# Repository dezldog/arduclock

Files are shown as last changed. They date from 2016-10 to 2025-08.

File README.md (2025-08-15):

# Instructions for `arduclock`

## Project Overview
This repository contains Arduino-based GPS clock projects with 7-segment displays. There are three main variants:
- `gps_clock_auto_timezone/`: GPS clock with automatic timezone detection based on GPS location.
- `gps_clock_tz_dst/`: GPS clock with manual DST and timezone selection via hardware pins.
- `original/`: Early version with manual UTC offset and DST toggle.

## Architecture & Key Files
- Each variant is a standalone `.ino` file, using similar hardware and libraries:
  - `Adafruit_LEDBackpack`, `Adafruit_GFX`, `Adafruit_GPS`, `SoftwareSerial`, `Wire`
- Hardware pins for timezone/DST selection are defined in each file (see `Config` namespace or `#define` macros).
- Display updates and GPS polling are managed via periodic intervals (see `DISPLAY_UPDATE_MS`, `TIMEZONE_CHECK_MS`, etc.).
- Timezone logic:
  - `gps_clock_auto_timezone`: Uses GPS coordinates to set timezone automatically.
  - `gps_clock_tz_dst`: Uses hardware pins for manual selection.
  - `original`: Uses fixed UTC offset and DST toggle.

## Developer Workflows
- **Build/Upload:**
  - Open the desired `.ino` file in the Arduino IDE or VS Code with Arduino extension.
  - Select the correct board and port, then upload as usual.
- **Debugging:**
  - Use `Serial.begin(115200)` for serial output (default baud rate).
  - Monitor serial output for GPS data and time updates.
- **Dependencies:**
  - Install required libraries via Arduino Library Manager:
    - Adafruit_LEDBackpack
    - Adafruit_GFX
    - Adafruit_GPS
    - SoftwareSerial
    - Wire (built-in)

## Project-Specific Patterns & Conventions
- **Pin Assignments:**
  - Timezone/DST selection pins are consistently assigned (see `Config` or macros).
  - GPS RX/TX pins: 8/7 (all variants).
- **Display Address:**
  - I2C address for display is `0x70`.
- **Time Format:**
  - 12-hour format by default (`TIME_24_HOUR = false`).
- **Serial Baud Rates:**
  - GPS: 9600
  - Serial Monitor: 115200
- **Update Intervals:**
  - Display: 100ms
  - Timezone check: 1s
  - Location check (auto mode): 30s

## Integration Points
- **External Services:**
  - No network/cloud integration; all logic is local to the Arduino.
- **PCB Files:**
  - Hardware design files in `original/` (`main_board.brd`, `.sch`).
  - Order PCBs via OSH Park (see README).

## Example: Adding a New Variant
- Copy an existing `.ino` file and update pin assignments, display logic, or timezone handling as needed.
- Follow the established pattern for hardware initialization and periodic updates.

## References
- Key files: `gps_clock_auto_timezone/gps_clock_auto_tz.ino`, `gps_clock_tz_dst/gps_clock_tz_dst.ino`, `original/clock_dst_tz.ino`
- Hardware: See `original/main_board.brd` and `.sch`
- README: Contains PCB ordering info and project links

---
**If any section is unclear or missing details, please provide feedback so this guide can be improved.**

View this project on [CADLAB.io](https://cadlab.io/node/898). 

# arduclock
PWBs available @

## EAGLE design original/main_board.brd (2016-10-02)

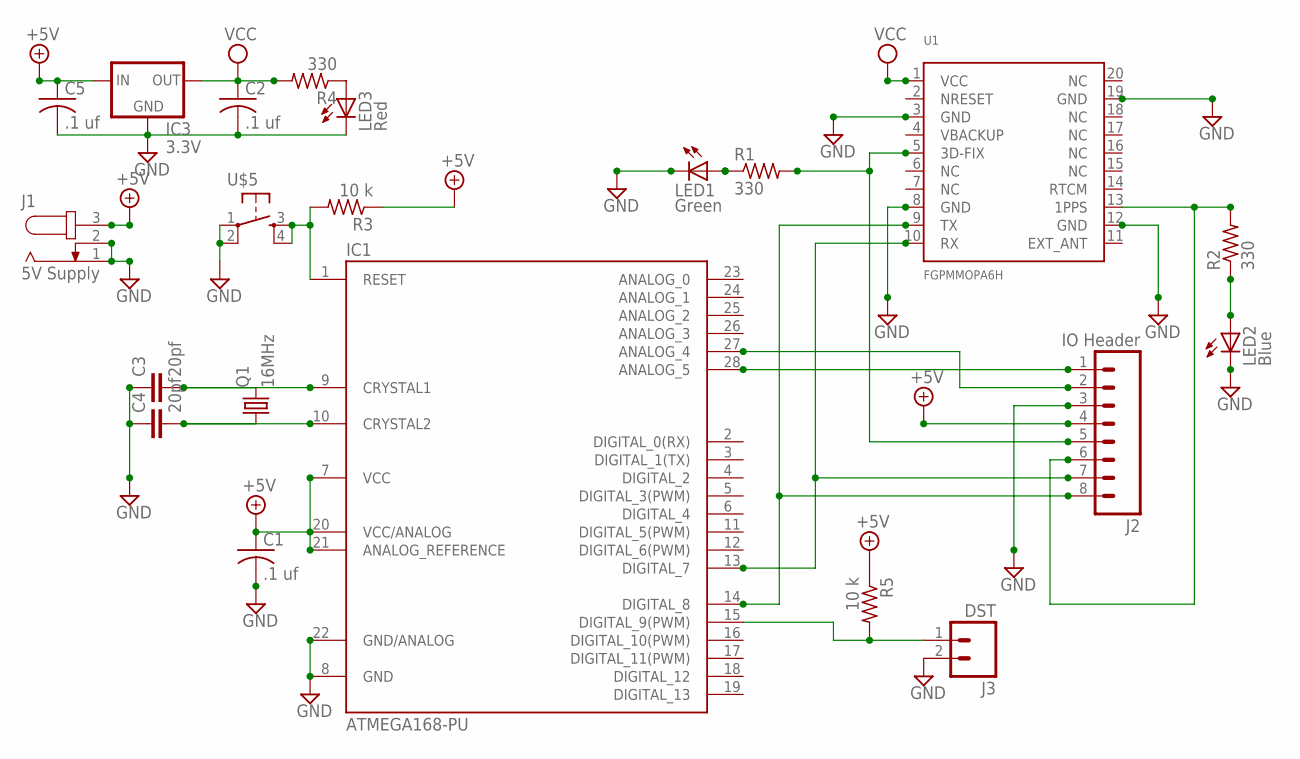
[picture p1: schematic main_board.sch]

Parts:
C1, C2, C5: .1 uf; C025-025X050
C3, C4: 20pf; C025-024X044
IC1: ATMEGA168-PU; DIL28-3
IC3: 3.3V; TO92
J1: 5V Supply; SPC4078
J2: IO Header; 1X08_ROUND
J3: DST; 1X02_LOCK
LED1: Green; LED3MM
LED2: Blue; LED3MM
LED3: Red; LED3MM
Q1: 16MHz; HC18U-V
R1, R2, R4: 330; 0204/5
R3, R5: 10 k; 0204/5
U1: FGPMMOPA6H
U$5: TACTILE-SWITCH-PTH; TAC-SWITCH-PTH

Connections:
+5V: C1.1, C5.1, IC1.7 (VCC), IC1.20 (VCC/ANALOG), IC1.21 (ANALOG_REFERENCE), IC3.2 (IN), J1.3, J2.4, R3.1, R5.1
DST: IC1.15 (DIGITAL_9(PWM)), J3.1, R5.2
GND: C1.2, C2.2, C3.1, C4.1, C5.2, IC1.8 (GND), IC1.22 (GND/ANALOG), IC3.1 (GND), J1.1, J1.2, J2.3, J3.2, LED1.K (C), LED2.K (C), LED3.K (C), U1.3 (GND), U1.8 (GND), U1.12 (GND), U1.19 (GND), U$5.1, U$5.2
unnamed: C4.2, IC1.10 (CRYSTAL2), Q1.1
unnamed: C3.2, IC1.9 (CRYSTAL1), Q1.2
unnamed: IC1.13 (DIGITAL_7), J2.7, U1.10 (RX)
unnamed: IC1.14 (DIGITAL_8), J2.8, U1.9 (TX)
unnamed: LED3.A, R4.1
unnamed: IC1.28 (ANALOG_5), J2.1
unnamed: IC1.1 (RESET), R3.2, U$5.3, U$5.4
unnamed: IC1.27 (ANALOG_4), J2.2
unnamed: J2.6, R2.2, U1.13 (1PPS)
unnamed: J2.5, R1.2, U1.5 (3D-FIX)
unnamed: LED1.A, R1.1
unnamed: LED2.A, R2.1
VCC: C2.1, IC3.3 (OUT), R4.2, U1.1 (VCC)

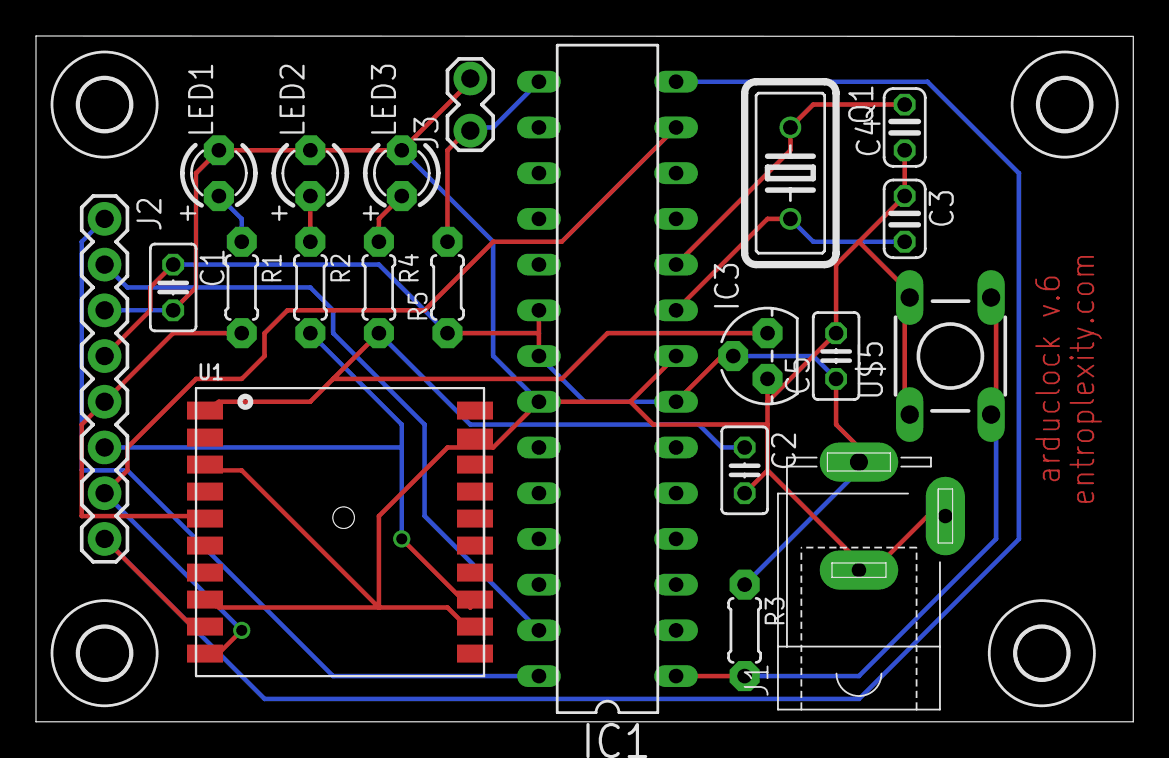
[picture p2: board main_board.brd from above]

Board: 2 copper layers, 61.0 x 38.1 mm, 25 parts (0 on the bottom side), 16 nets.

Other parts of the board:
U$1, U$2, U$3, U$4: 2,8

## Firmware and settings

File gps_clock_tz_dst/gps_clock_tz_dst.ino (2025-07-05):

/**
 * GPS Clock with 7-Segment Display
 * and DST/TimeZone selector
 */

#include "SoftwareSerial.h"
#include "Wire.h"
#include "Adafruit_LEDBackpack.h"
#include "Adafruit_GFX.h"
#include "Adafruit_GPS.h"

// Configuration Constants
namespace Config {
  // Display settings
  const bool TIME_24_HOUR = false;
  const uint8_t DISPLAY_ADDRESS = 0x70;
  
  // Time zone settings
  const uint8_t DST_PIN = 9;           // Pin for DST switch
  const uint8_t TIMEZONE_PIN_A = 10;   // Pin A for timezone selection
  const uint8_t TIMEZONE_PIN_B = 11;   // Pin B for timezone selection
  const uint8_t TIMEZONE_PIN_C = 12;   // Pin C for timezone selection
  
  // GPS settings
  const uint8_t GPS_RX_PIN = 8;
  const uint8_t GPS_TX_PIN = 7;
  const uint32_t GPS_BAUD = 9600;
  const uint32_t SERIAL_BAUD = 115200;
  
  // Update intervals
  const uint16_t DISPLAY_UPDATE_MS = 100;
  const uint16_t TIMEZONE_CHECK_MS = 1000;  // Check timezone switches every second
}

// Hardware instances
Adafruit_7segment display = Adafruit_7segment();
SoftwareSerial gpsSerial(Config::GPS_RX_PIN, Config::GPS_TX_PIN);
Adafruit_GPS gps(&gpsSerial);

// Timezone definitions
struct Timezone {
  const char* name;
  const char* abbreviation;
  int8_t utcOffset;        // Standard time offset from UTC
  bool observesDST;        // Whether this timezone observes DST
  int8_t dstOffset;        // Additional offset during DST (usually +1)
};

// Predefined timezones (expandable)
const Timezone TIMEZONES[] = {
  {"Pacific Standard", "PST", -8, true, 1},      // 000
  {"Mountain Standard", "MST", -7, true, 1},     // 001
  {"Central Standard", "CST", -6, true, 1},      // 010
  {"Eastern Standard", "EST", -5, true, 1},      // 011
  {"Atlantic Standard", "AST", -4, false, 0},    // 100
  {"Hawaii Standard", "HST", -10, false, 0},     // 101
  {"Alaska Standard", "AKST", -9, true, 1},      // 110
  {"UTC", "UTC", 0, false, 0}                    // 111
};

const uint8_t NUM_TIMEZONES = sizeof(TIMEZONES) / sizeof(TIMEZONES[0]);

// State variables
struct ClockState {
  uint32_t lastUpdate = 0;
  uint32_t lastTimezoneCheck = 0;
  bool colonState = false;
  bool gpsFixValid = false;
  uint8_t hours = 0;
  uint8_t minutes = 0;
  uint8_t seconds = 0;
  uint8_t currentTimezoneIndex = 0;
  bool isDSTActive = false;
  bool dstSwitchState = false;
  uint8_t timezoneSwitchState = 0;
} clockState;

/**
 * Initialize all hardware components
 */
void setup() {
  Serial.begin(Config::SERIAL_BAUD);
  Serial.println(F("GPS Clock Starting..."));
  
  initializeDisplay();
  initializeGPS();
  initializePins();
  
  Serial.println(F("Initialization complete"));
}

/**
 * Main program loop
 */
void loop() {
  updateGPSData();
  updateTimezoneIfNeeded();
  
  if (millis() - clockState.lastUpdate >= Config::DISPLAY_UPDATE_MS) {
    updateDisplay();
    clockState.lastUpdate = millis();
  }
}

/**
 * Initialize the 7-segment display
 */
void initializeDisplay() {
  display.begin(Config::DISPLAY_ADDRESS);
  display.setBrightness(15);  // Max brightness
  
  // Show startup pattern
  display.print(8888);
  display.drawColon(true);
  display.writeDisplay();
  delay(1000);
  display.clear();
  display.writeDisplay();
}

/**
 * Initialize GPS module
 */
void initializeGPS() {
  gps.begin(Config::GPS_BAUD);
  
  // Configure GPS for optimal clock usage
  gps.sendCommand(PMTK_SET_NMEA_OUTPUT_RMCONLY);
  gps.sendCommand(PMTK_SET_NMEA_UPDATE_1HZ);
  
  enableGPSInterrupt();
  
  Serial.println(F("Waiting for GPS fix..."));
}

/**
 * Initialize input pins
 */
void initializePins() {
  pinMode(Config::DST_PIN, INPUT_PULLUP);
  pinMode(Config::TIMEZONE_PIN_A, INPUT_PULLUP);
  pinMode(Config::TIMEZONE_PIN_B, INPUT_PULLUP);
  pinMode(Config::TIMEZONE_PIN_C, INPUT_PULLUP);
  
  // Initialize timezone state
  updateTimezoneSettings();
  
  Serial.print(F("Initial timezone: "));
  Serial.println(getCurrentTimezone().name);
}

/**
 * Update GPS data if available
 */
void updateGPSData() {
  if (gps.newNMEAreceived()) {
    if (gps.parse(gps.lastNMEA())) {
      clockState.gpsFixValid = gps.fix;
      
      if (clockState.gpsFixValid) {
        updateTimeFromGPS();
      }
    }
  }
}

/**
 * Extract and adjust time from GPS data
 */
void updateTimeFromGPS() {
  int totalOffset = calculateTimezoneOffset();
  int adjustedHours = gps.hour + totalOffset;
  
  // Handle day boundary crossings
  adjustedHours = normalizeHours(adjustedHours);
  
  clockState.hours = adjustedHours;
  clockState.minutes = gps.minute;
  clockState.seconds = gps.seconds;
}

/**
 * Normalize hours to 0-23 range, handling day boundaries
 */
int normalizeHours(int hours) {
  while (hours < 0) {
    hours += 24;
  }
  while (hours >= 24) {
    hours -= 24;
  }
  return hours;
}

/**
 * Update the display with current time
 */
void updateDisplay() {
  if (!clockState.gpsFixValid) {
    showNoGPSIndicator();
    return;
  }
  
  int displayHours = clockState.hours;
  int displayValue;
  
  // Convert to 12-hour format if needed
  if (!Config::TIME_24_HOUR) {
    displayHours = convertTo12Hour(displayHours);
  }
  
  displayValue = displayHours * 100 + clockState.minutes;
  
  // Display the time
  display.print(displayValue, DEC);
  
  // Handle leading zeros for 24-hour format
  if (Config::TIME_24_HOUR && clockState.hours < 10) {
    display.writeDigitNum(1, 0);
    if (clockState.minutes < 10) {
      display.writeDigitNum(3, 0);
    }
  }
  
  // Blink colon every second
  bool showColon = (clockState.seconds % 2 == 0);
  display.drawColon(showColon);
  
  display.writeDisplay();
}

/**
 * Convert 24-hour format to 12-hour format
 */
int convertTo12Hour(int hours24) {
  if (hours24 == 0) {
    return 12;  // Midnight becomes 12 AM
  } else if (hours24 > 12) {
    return hours24 - 12;  // PM hours
  } else {
    return hours24;  // AM hours (1-12)
  }
}

/**
 * Show indicator when GPS fix is not available
 */
void showNoGPSIndicator() {
  static uint32_t lastBlink = 0;
  static bool blinkState = false;
  
  if (millis() - lastBlink >= 500) {  // Blink every 500ms
    blinkState = !blinkState;
    lastBlink = millis();
    
    if (blinkState) {
      display.print(0);  // Show "00.00"
      display.drawColon(true);
    } else {
      display.clear();
    }
    display.writeDisplay();
  }
}

/**
 * Get timezone offset in hours
 */
int getTimezoneOffset() {
  return getCurrentTimezone().utcOffset;
}

/**
 * Get DST offset based on switch state
 */
int getDSTOffset() {
  const Timezone& tz = getCurrentTimezone();
  
  if (!tz.observesDST) {
    return 0;  // This timezone doesn't observe DST
  }
  
  return clockState.isDSTActive ? tz.dstOffset : 0;
}

/**
 * Calculate total timezone offset including DST
 */
int calculateTimezoneOffset() {
  return getTimezoneOffset() + getDSTOffset();
}

/**
 * Get current timezone object
 */
const Timezone& getCurrentTimezone() {
  return TIMEZONES[clockState.currentTimezoneIndex];
}

/**
 * Update timezone settings based on switches
 */
void updateTimezoneSettings() {
  // Read timezone selector switches (3-bit binary)
  uint8_t newTimezoneState = 0;
  if (digitalRead(Config::TIMEZONE_PIN_A) == LOW) newTimezoneState |= 0x01;
  if (digitalRead(Config::TIMEZONE_PIN_B) == LOW) newTimezoneState |= 0x02;
  if (digitalRead(Config::TIMEZONE_PIN_C) == LOW) newTimezoneState |= 0x04;
  
  // Read DST switch
  bool newDSTState = (digitalRead(Config::DST_PIN) == LOW);
  
  // Check if timezone changed
  if (newTimezoneState != clockState.timezoneSwitchState) {
    clockState.timezoneSwitchState = newTimezoneState;
    clockState.currentTimezoneIndex = newTimezoneState % NUM_TIMEZONES;
    
    Serial.print(F("Timezone changed to: "));
    Serial.print(getCurrentTimezone().name);
    Serial.print(F(" ("));
    Serial.print(getCurrentTimezone().abbreviation);
    Serial.println(F(")"));
  }
  
  // Check if DST setting changed
  if (newDSTState != clockState.dstSwitchState) {
    clockState.dstSwitchState = newDSTState;
    clockState.isDSTActive = newDSTState;
    
    Serial.print(F("DST "));
    Serial.println(clockState.isDSTActive ? F("ON") : F("OFF"));
  }
}

/**
 * Check and update timezone settings periodically
 */
void updateTimezoneIfNeeded() {
  if (millis() - clockState.lastTimezoneCheck >= Config::TIMEZONE_CHECK_MS) {
    updateTimezoneSettings();
    clockState.lastTimezoneCheck = millis();
  }
}

/**
 * Get timezone name for display
 */
String getTimezoneDisplayName() {
  const Timezone& tz = getCurrentTimezone();
  String name = tz.abbreviation;
  
  if (tz.observesDST && clockState.isDSTActive) {
    // Convert standard time abbreviation to DST
    // This is a simplified conversion - could be expanded
    if (name == "PST") name = "PDT";
    else if (name == "MST") name = "MDT";
    else if (name == "CST") name = "CDT";
    else if (name == "EST") name = "EDT";
    else if (name == "AKST") name = "AKDT";
    else name += "D";  // Generic DST indicator
  }
  
  return name;
}

/**
 * Auto-detect DST based on date (US rules)
 * Call this function if you want automatic DST detection
 */
bool calculateDSTAuto() {
  if (!clockState.gpsFixValid) return false;
  
  const Timezone& tz = getCurrentTimezone();
  if (!tz.observesDST) return false;
  
  // This is a simplified US DST calculation
  // DST starts second Sunday in March, ends first Sunday in November
  // For full implementation, you'd need to calculate based on GPS date
  
  uint8_t month = gps.month;
  uint8_t day = gps.day;
  
  // Very basic DST detection (US rules)
  if (month >= 4 && month <= 10) {
    return true;  // Likely DST period
  } else if (month == 3) {
    return day >= 8;  // Rough approximation
  } else if (month == 11) {
    return day < 7;   // Rough approximation
  }
  
  return false;
}

/**
 * Enable GPS interrupt for data reading
 */
void enableGPSInterrupt() {
  OCR0A = 0xAF;
  TIMSK0 |= _BV(OCIE0A);
}

/**
 * GPS interrupt service routine
 */
SIGNAL(TIMER0_COMPA_vect) {
  gps.read();
}

/**
 * Debug function to print current status
 */
void printStatus() {
  Serial.print(F("GPS Fix: "));
  Serial.print(clockState.gpsFixValid ? F("YES") : F("NO"));
  
  if (clockState.gpsFixValid) {
    Serial.print(F(" | Time: "));
    if (clockState.hours < 10) Serial.print('0');
    Serial.print(clockState.hours);
    Serial.print(':');
    if (clockState.minutes < 10) Serial.print('0');
    Serial.print(clockState.minutes);
    Serial.print(':');
    if (clockState.seconds < 10) Serial.print('0');
    Serial.print(clockState.seconds);
    
    Serial.print(F(" "));
    Serial.print(getTimezoneDisplayName());
    
    Serial.print(F(" | Satellites: "));
    Serial.print((int)gps.satellites);
    
    Serial.print(F(" | Date: "));
    Serial.print(gps.month);
    Serial.print('/');
    Serial.print(gps.day);
    Serial.print('/');
    Serial.print(2000 + gps.year);
  }
  
  Serial.print(F(" | TZ: "));
  Serial.print(getCurrentTimezone().name);
  Serial.print(F(" (UTC"));
  int totalOffset = calculateTimezoneOffset();
  if (totalOffset >= 0) Serial.print('+');
  Serial.print(totalOffset);
  Serial.print(F(")"));
  
  Serial.println();
}

/**
 * Display timezone information on startup or timezone change
 */
void displayTimezoneInfo() {
  const Timezone& tz = getCurrentTimezone();
  
  Serial.println(F("=== Timezone Information ==="));
  Serial.print(F("Name: "));
  Serial.println(tz.name);
  Serial.print(F("Abbreviation: "));
  Serial.println(getTimezoneDisplayName());
  Serial.print(F("UTC Offset: "));
  if (tz.utcOffset >= 0) Serial.print('+');
  Serial.println(tz.utcOffset);
  Serial.print(F("Observes DST: "));
  Serial.println(tz.observesDST ? F("Yes") : F("No"));
  if (tz.observesDST) {
    Serial.print(F("DST Currently: "));
    Serial.println(clockState.isDSTActive ? F("Active") : F("Inactive"));
  }
  Serial.print(F("Total Offset: UTC"));
  int totalOffset = calculateTimezoneOffset();
  if (totalOffset >= 0) Serial.print('+');
  Serial.println(totalOffset);
  Serial.println(F("============================"));
}

/**
 * List all available timezones
 */
void listAvailableTimezones() {
  Serial.println(F("Available Timezones:"));
  Serial.println(F("Switch | Name | Abbrev | UTC Offset"));
  Serial.println(F("-------|------|--------|----------"));
  
  for (uint8_t i = 0; i < NUM_TIMEZONES; i++) {
    Serial.print(F("  "));
    Serial.print(i, BIN);
    if (i < 4) Serial.print(F("  "));  // Align binary display
    Serial.print(F("   | "));
    Serial.print(TIMEZONES[i].name);
    Serial.print(F(" | "));
    Serial.print(TIMEZONES[i].abbreviation);
    Serial.print(F(" | UTC"));
    if (TIMEZONES[i].utcOffset >= 0) Serial.print('+');
    Serial.print(TIMEZONES[i].utcOffset);
    if (TIMEZONES[i].observesDST) {
      Serial.print(F(" (DST +"));
      Serial.print(TIMEZONES[i].dstOffset);
      Serial.print(F(")"));
    }
    Serial.println();
  }
  Serial.println();
}

/**
 * Convert UTC time to any timezone
 */
void convertUTCToTimezone(uint8_t utcHour, uint8_t utcMinute, uint8_t timezoneIndex, 
                         uint8_t& localHour, uint8_t& localMinute, bool useDST = false) {
  if (timezoneIndex >= NUM_TIMEZONES) return;
  
  const Timezone& tz = TIMEZONES[timezoneIndex];
  int offset = tz.utcOffset;
  
  if (useDST && tz.observesDST) {
    offset += tz.dstOffset;
  }
  
  int totalMinutes = utcHour * 60 + utcMinute + (offset * 60);
  
  // Handle day boundary crossings
  while (totalMinutes < 0) totalMinutes += 24 * 60;
  while (totalMinutes >= 24 * 60) totalMinutes -= 24 * 60;
  
  localHour = totalMinutes / 60;
  localMinute = totalMinutes % 60;
}

/**
 * Show multiple timezone clocks (useful for world clock feature)
 */
void showWorldClock() {
  if (!clockState.gpsFixValid) {
    Serial.println(F("No GPS fix for world clock"));
    return;
  }
  
  Serial.println(F("=== World Clock ==="));
  Serial.print(F("UTC: "));
  if (gps.hour < 10) Serial.print('0');
  Serial.print(gps.hour);
  Serial.print(':');
  if (gps.minute < 10) Serial.print('0');
  Serial.println(gps.minute);
  Serial.println();
  
  for (uint8_t i = 0; i < NUM_TIMEZONES; i++) {
    uint8_t localHour, localMinute;
    convertUTCToTimezone(gps.hour, gps.minute, i, localHour, localMinute, true);
    
    Serial.print(TIMEZONES[i].abbreviation);
    Serial.print(F(": "));
    if (localHour < 10) Serial.print('0');
    Serial.print(localHour);
    Serial.print(':');
    if (localMinute < 10) Serial.print('0');
    Serial.print(localMinute);
    Serial.print(F(" ("));
    Serial.print(TIMEZONES[i].name);
    Serial.println(F(")"));
  }
  Serial.println(F("=================="));
}

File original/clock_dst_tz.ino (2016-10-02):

///A quick variation on the Adafruit code
///

#include "SoftwareSerial.h"
#include "Wire.h"
#include "Adafruit_LEDBackpack.h"
#include "Adafruit_GFX.h"
#include "Adafruit_GPS.h"

// Set to false to display time in 12 hour format, or true to use 24 hour:
#define TIME_24_HOUR      false

// Offset the hours from UTC (universal time) to your local time by changing
// this value.  The GPS time will be in UTC so lookup the offset for your
// local time from a site like:
//   https://en.wikipedia.org/wiki/List_of_UTC_time_offsets
// This value, -7, will set the time to UTC-7 or Pacific Standard Time during
// daylight savings time.
#define HOUR_OFFSET       -8

// Is it DST?
#define DST 0
const int dstPin = 9;
int dstON = 0;


#define DISPLAY_ADDRESS   0x70

Adafruit_7segment clockDisplay = Adafruit_7segment();

SoftwareSerial gpsSerial(8, 7);  

Adafruit_GPS gps(&gpsSerial);

int displayValue = 0;


void setup() {

  Serial.begin(115200);
  clockDisplay.begin(DISPLAY_ADDRESS);
  gps.begin(9600);
  gps.sendCommand(PMTK_SET_NMEA_OUTPUT_RMCONLY);
  gps.sendCommand(PMTK_SET_NMEA_UPDATE_1HZ);
  enableGPSInterrupt();
  pinMode(dstPin, INPUT);
  }

void loop() {

  if (gps.newNMEAreceived()) {
    gps.parse(gps.lastNMEA());
  }
  
  int hours = gps.hour + timeZone() + isDST();

  if (hours < 0) {
    hours = 24+hours;
  }
  if (hours > 23) {
    hours = 24-hours;
  }
int minutes = gps.minute;
int seconds = gps.seconds;
  
displayValue = hours*100 + minutes;

  if (!TIME_24_HOUR) {
    if (hours > 12) {
      displayValue -= 1200;
    }
    else if (hours == 0) {
      displayValue += 1200;
    }
  }

  clockDisplay.print(displayValue, DEC);

  if (TIME_24_HOUR && hours == 0) {
    clockDisplay.writeDigitNum(1, 0);
    if (minutes < 10) {
      clockDisplay.writeDigitNum(2, 0);
    }
  }

  clockDisplay.drawColon(seconds % 2 == 0);

  clockDisplay.writeDisplay();

}

SIGNAL(TIMER0_COMPA_vect) {
  gps.read();
}

void enableGPSInterrupt() {
  OCR0A = 0xAF;
  TIMSK0 |= _BV(OCIE0A);
}

int isDST()
{
  dstON = digitalRead(dstPin);
  if (dstON == HIGH)
    {
      return 1;
    } 
  else
    {
      return 0;
    }
}

int timeZone()
  {
    return HOUR_OFFSET;
  }

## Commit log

2016-10-02 Kinda self-documented. Enough for a non-novice to build.
    [main_board.brd, main_board.sch]
2025-07-05 Organizing and adding new code with time zone and dst switch
    [main_board.brd, main_board.sch]
2025-07-05 more organizing
    [main_board.brd, main_board.sch]

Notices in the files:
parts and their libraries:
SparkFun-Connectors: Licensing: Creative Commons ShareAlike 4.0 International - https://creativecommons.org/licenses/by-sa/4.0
